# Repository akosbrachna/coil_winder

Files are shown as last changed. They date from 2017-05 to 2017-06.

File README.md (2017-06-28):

# coil_winder

MPLAB project

The circuit consists of 

1x PIC18F2550 microcontroller, 

2x L293D motor drivers, 

1x MAX232 serial port chip, 

2x nema 17 stepper motors

One motor is winding the coil while the other one is moving a guider forth and back along the width of the core
to aid laying the wire side by side on the core.

The microcontroller receives the coil parameters on serial port from a windows program 
that provides the user interface for the circuit. https://github.com/akosbrachna/coil_winder_interface

Future plan is to add a current sensor resistor on the high voltage input that will be connected to the analog comparator 
of the microcontroller. The microcontroller through a power transistor would limit the input current on the drivers
if the current exceeds the specified current of the drivers.

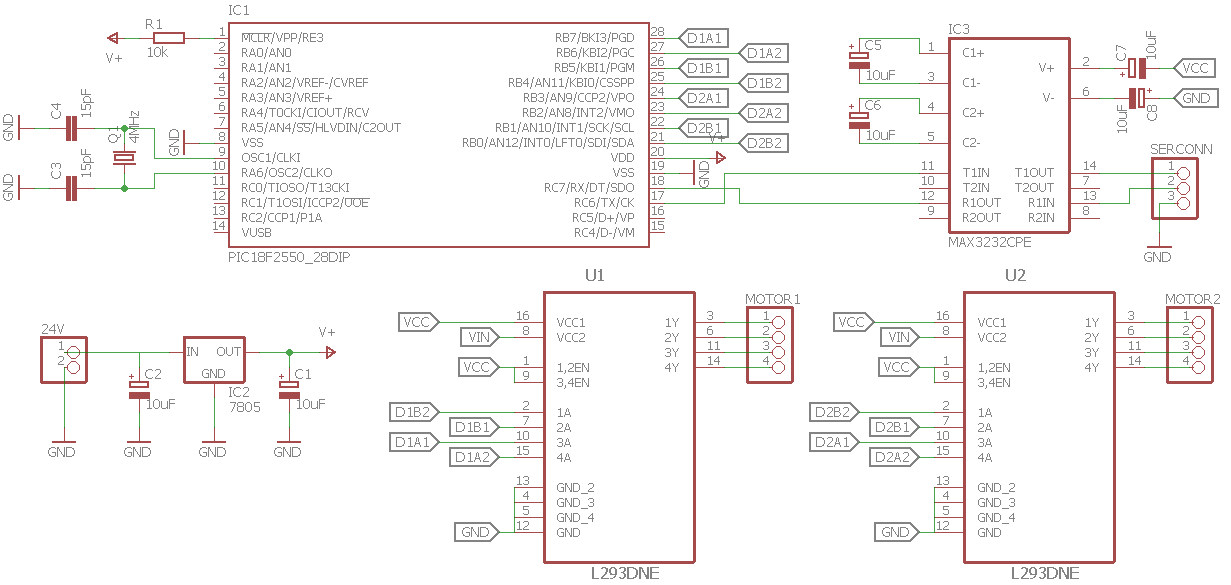
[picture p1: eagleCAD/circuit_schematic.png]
Circuit schematic


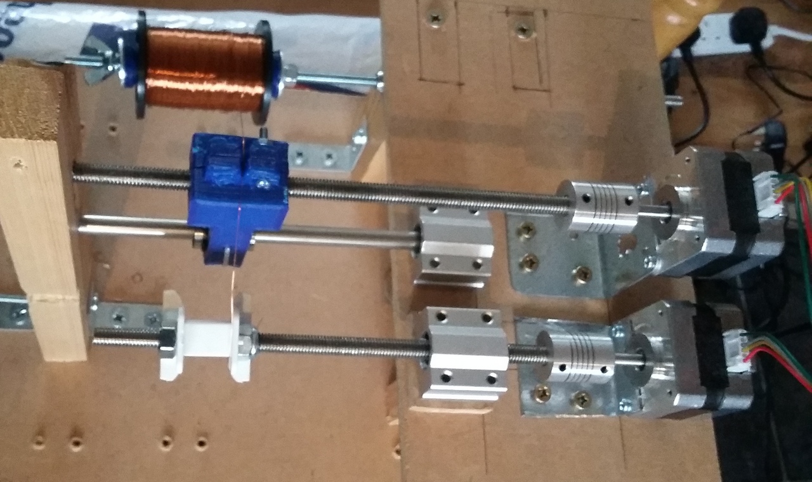
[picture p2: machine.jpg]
Machine


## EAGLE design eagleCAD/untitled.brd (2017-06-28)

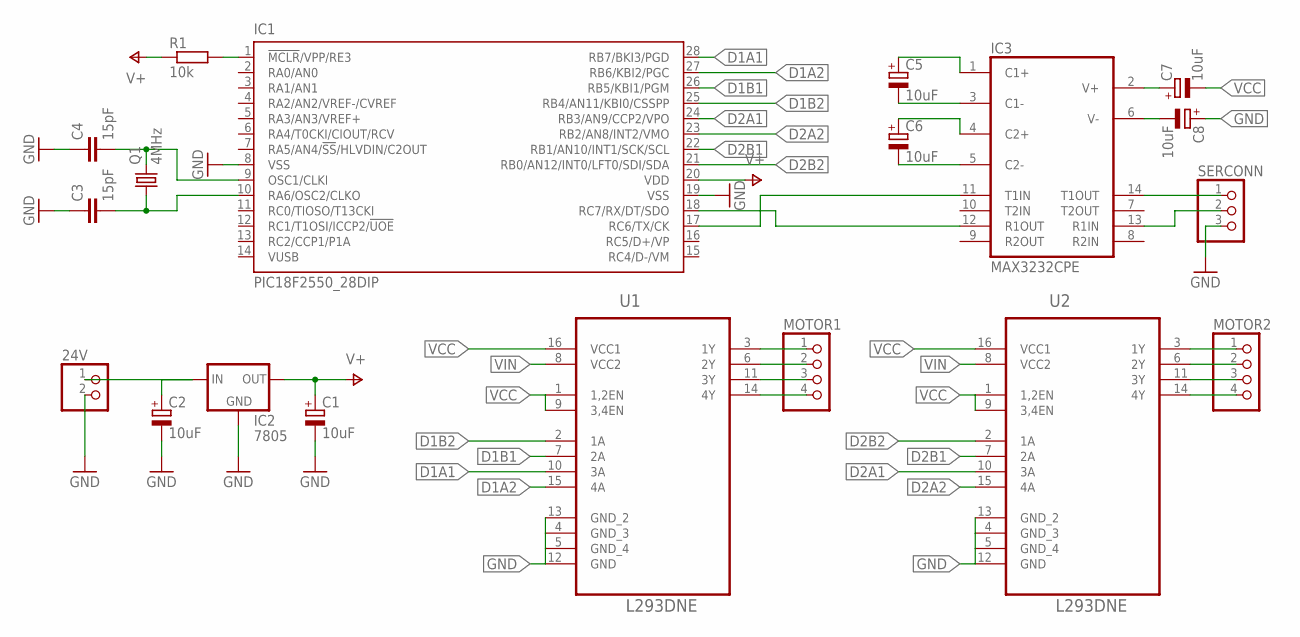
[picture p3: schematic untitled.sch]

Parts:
24V: PINHD-1X2; 1X02
C1, C2, C5, C6, C7, C8: 10uF; E2,5-6; MPN 100PK10MEFC5X11
C3, C4: 15pF; C7.5B6; MPN 08051A150JAT2A
IC1: PIC18F2550_28DIP; DIL28-3
IC2: 7805; 78XXL; MPN L7805ACV
IC3: MAX3232CPE; DIL16
MOTOR1, MOTOR2: PINHD-1X4; 1X04
Q1: 4MHz; HC49/S; MPN HC49US4.000MABJ-UB
R1: 10k; 0309/12; MPN CR0805-FX-1002ELF
SERCONN: PINHD-1X3; 1X03
U1, U2: L293DNE; DIP254P762X508-16

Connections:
D1A1: IC1.28 (RB7/BKI3/PGD), U1.10 (3A)
D1A2: IC1.27 (RB6/KBI2/PGC), U1.15 (4A)
D1B1: IC1.26 (RB5/KBI1/PGM), U1.7 (2A)
D1B2: IC1.25 (RB4/AN11/KBI0/CSSPP), U1.2 (1A)
D2A1: IC1.24 (RB3/AN9/CCP2/VPO), U2.10 (3A)
D2A2: IC1.23 (RB2/AN8/INT2/VMO), U2.15 (4A)
D2B1: IC1.22 (RB1/AN10/INT1/SCK/SCL), U2.7 (2A)
D2B2: IC1.21 (RB0/AN12/INT0/LFT0/SDI/SDA), U2.2 (1A)
GND: 24V.2, C1.-, C2.-, C3.1, C4.1, C8.+, IC1.8 (VSS), IC1.19 (VSS), IC2.GND, IC3.15 (GND), SERCONN.3, U1.4 (GND_3), U1.5 (GND_4), U1.12 (GND), U1.13 (GND_2), U2.4 (GND_3), U2.5 (GND_4), U2.12 (GND), U2.13 (GND_2)
unnamed: C4.2, IC1.9 (OSC1/CLKI), Q1.2
unnamed: C3.2, IC1.10 (RA6/OSC2/CLKO), Q1.1
unnamed: IC3.14 (T1OUT), SERCONN.1
unnamed: C7.+, IC3.2 (V+)
unnamed: C8.-, IC3.6 (V-)
unnamed: C5.-, IC3.3 (C1-)
unnamed: C5.+, IC3.1 (C1+)
unnamed: C6.-, IC3.5 (C2-)
unnamed: C6.+, IC3.4 (C2+)
unnamed: IC1.18 (RC7/RX/DT/SDO), IC3.12 (R1OUT)
unnamed: IC1.17 (RC6/TX/CK), IC3.11 (T1IN)
unnamed: MOTOR1.3, U1.11 (3Y)
unnamed: MOTOR1.4, U1.14 (4Y)
unnamed: MOTOR1.1, U1.3 (1Y)
unnamed: IC1.1 (!MCLR!/VPP/RE3), R1.2
unnamed: IC3.13 (R1IN), SERCONN.2
unnamed: MOTOR1.2, U1.6 (2Y)
unnamed: MOTOR2.1, U2.3 (1Y)
unnamed: MOTOR2.2, U2.6 (2Y)
unnamed: MOTOR2.3, U2.11 (3Y)
unnamed: MOTOR2.4, U2.14 (4Y)
V+: R1.1
VCC: C1.+, C7.-, IC1.20 (VDD), IC2.OUT, IC3.16 (VCC), U1.1 (1,2EN), U1.9 (3,4EN), U1.16 (VCC1), U2.1 (1,2EN), U2.9 (3,4EN), U2.16 (VCC1)
VIN: 24V.1, C2.+, IC2.IN, U1.8 (VCC2), U2.8 (VCC2)

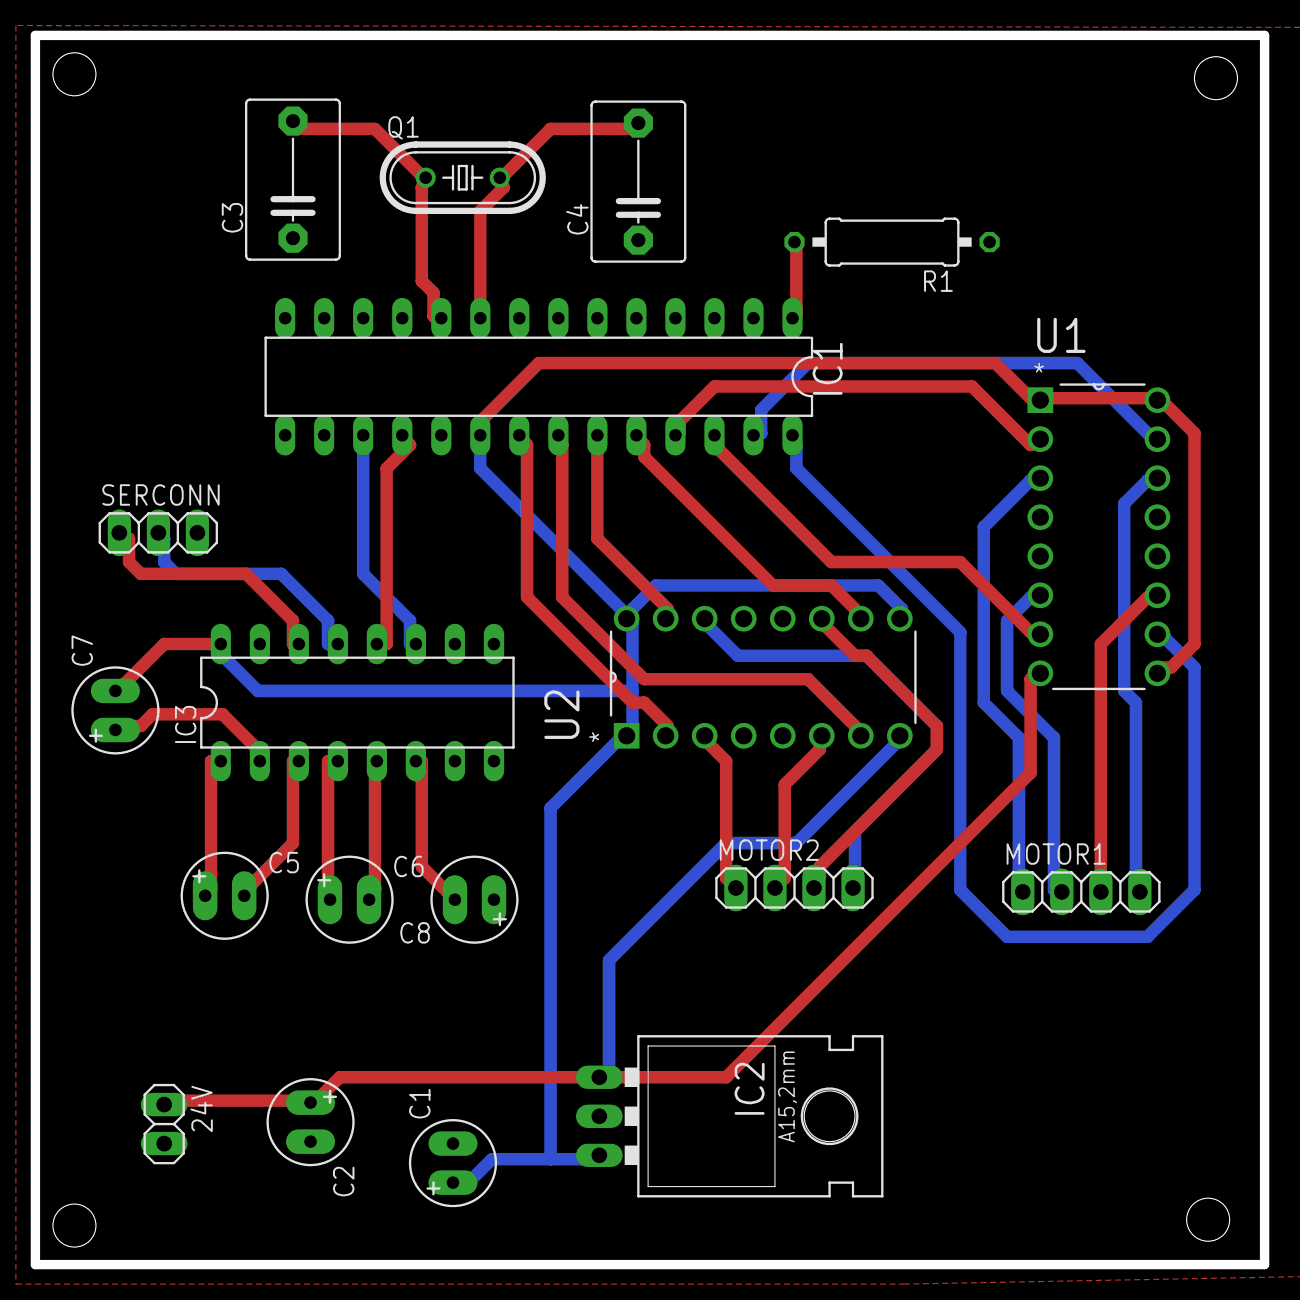
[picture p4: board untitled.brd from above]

Board: 2 copper layers, 80.0 x 80.0 mm, 19 parts (0 on the bottom side), 32 nets.

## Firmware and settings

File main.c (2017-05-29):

unsigned int wire_thickness = 0;
unsigned int coil_width = 0;
unsigned int number_of_turns = 0;
unsigned int rotation_speed = 0;

unsigned int turn_counter = 0;
unsigned char counter[7];

volatile unsigned int steps_per_coil_width;
volatile unsigned int round = 0;

volatile unsigned char rcbuf[25];
volatile unsigned char rcindex = 0;
volatile unsigned char t;

#include <p18f2550.h>
#include <delays.h>
#include <stdlib.h>
#include "config4.h"
#include "std_lib.h"
#include "timers.h"
#include "serial.h"
#include "stepper.h"
#include "interrupt.h"

void main(void)
{
    TRISB = 0x00;
	LATB = 0;
	CMCON = 0x07;  // turn off comparators
	ADCON1 = 0x06; // turn off analog to digital converters

	reset_array(rcbuf, 12);

    usart_init();
    usart_puts("Connection to winder is successful.\n");

	RCONbits.IPEN = 1;
	IPR1bits.RCIP = 0;
	IPR1bits.TXIP = 0;
	INTCON2bits.TMR0IP = 1;
    INTCONbits.PEIE = 1;
    INTCONbits.GIE = 1;

	while (number_of_turns == 0);

	//disable_serial_port();
	if (rotation_speed > 5 && rotation_speed < 40)
	{
		motor1_step_time = (unsigned int)(1000.0/((float)rotation_speed));
	}
	else motor1_step_time = 100;
	motor2_step_time = (unsigned int)((float)motor1_step_time*(float)(1250.0/(float)wire_thickness));
	steps_per_coil_width = (unsigned int)(200*coil_width/1.25);
	
	init_timer0();

	while(1)
	{
		if (number_of_turns_motor1 >= number_of_turns)
		{
			stop_timer0();
			if (turn_counter != number_of_turns_motor1)
			{
				int_to_string(number_of_turns_motor1, counter);
				usart_put_array(counter);
			}
			usart_puts(" turns...job finished.\n");
			INTCONbits.PEIE = 0;
    		INTCONbits.GIE = 0;
			LATB = 0;
			number_of_turns_motor1 = 0;
		}
		else
		{
			if (number_of_turns_motor1 > turn_counter)
			{
				turn_counter = number_of_turns_motor1;
				int_to_string(turn_counter, counter);
				usart_put_array(counter);
			}
		}
	}
}

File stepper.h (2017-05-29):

#define forward 0
#define backward 1
// bipolar 2 phase full step
unsigned char steps2[] = {0b00000101, 
						  0b00000110,
						  0b00001010,
						  0b00001001};

// MOTOR 1
// bipolar 1 phase full step
// forward
unsigned char steps1f[] = {0b00000001, 
						   0b00000100,
				   		   0b00000010,
						   0b00001000};
// backward
unsigned char steps1b[] = {0b00000001, 
						   0b00001000,
				   		   0b00000010,
						   0b00000100};
// MOTOR 2
// bipolar 1 phase full step
// forward
unsigned char steps1f_motor2[] = {0b00010000, 
						   		  0b01000000,
				   		   		  0b00100000,
						   		  0b10000000};
// backward
unsigned char steps1b_motor2[] = {0b00010000, 
						   		  0b10000000,
				   		   		  0b00100000,
						   		  0b01000000};

unsigned int motor1_step_time = 100;
volatile unsigned int motor1_current_step = 0;
volatile unsigned char motor1_step_index = 0;
volatile unsigned int number_of_steps_motor1 = 0;
volatile unsigned int number_of_turns_motor1 = 0;

unsigned int motor2_step_time;
volatile unsigned int motor2_current_step = 0;
volatile unsigned char motor2_step_index = 0;
volatile unsigned char motor2_direction = forward;

volatile unsigned char temp_motor;
